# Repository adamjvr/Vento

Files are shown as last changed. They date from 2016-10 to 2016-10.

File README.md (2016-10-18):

# Vento
ARM Cortex M4F + WiFi+BLE + MPPT Solar Battery Powered module, mBed and Arduino Compatible hardware development
- ARM Cortex M4F 180MHZ STM32F446RET6
- ESP32 WiFi/BLE Dual Core SoC w/ PCB Antenna
- Bluetooth Classic
- Bluetooth Low Engergy (BLE)
- WiFi
- USB 2.0 Connectivity
- Plenty of GPIO
- PLenty of UART/I2C
- Lithium Ion Battery Power
- MPPT Solar battery charging
- USB bus power for desktop development
- Over the Air Programming
- Low power
- 2 Year Battery Life w/Single Cell Lithium Battery

Vento 0.1a KiCAD PCB
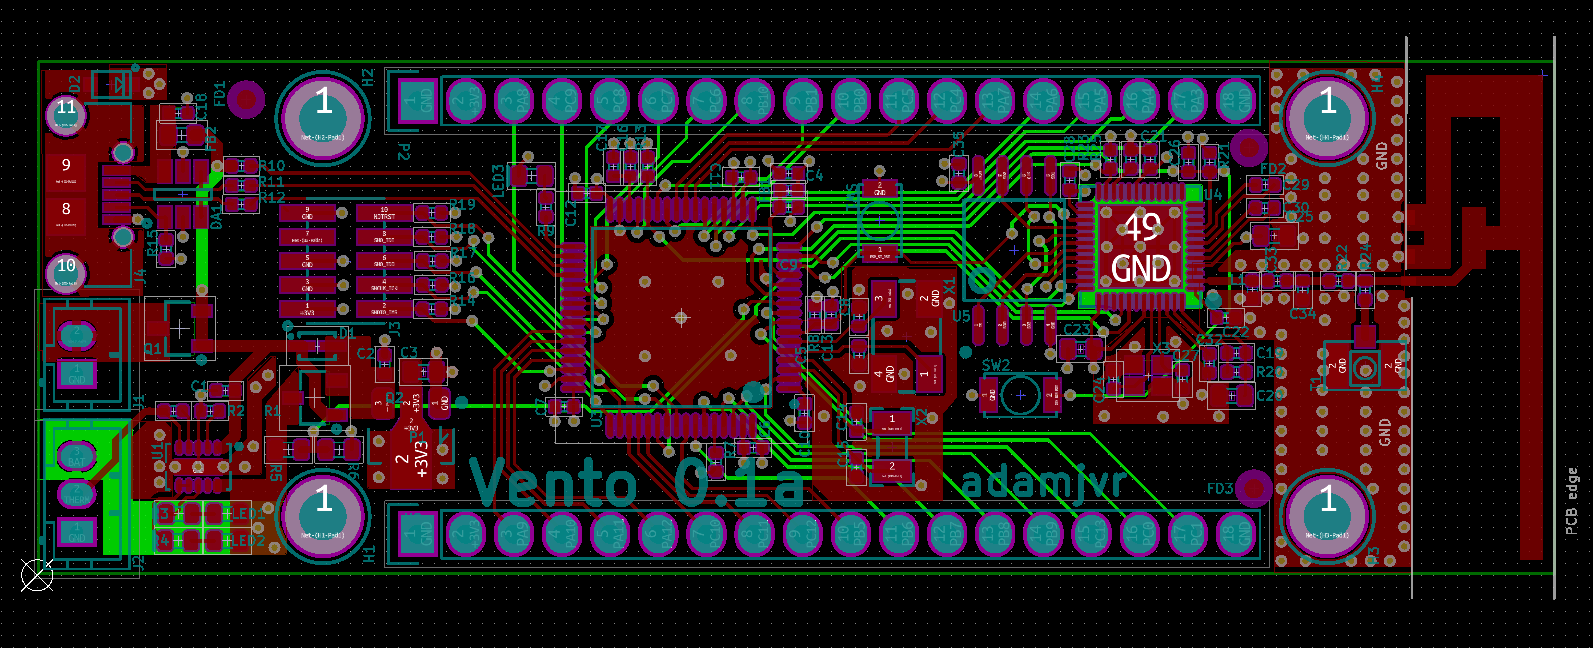
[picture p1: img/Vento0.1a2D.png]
Vento 0.1a KiCAD PCB

KiCAD PCB 3D Render
Top
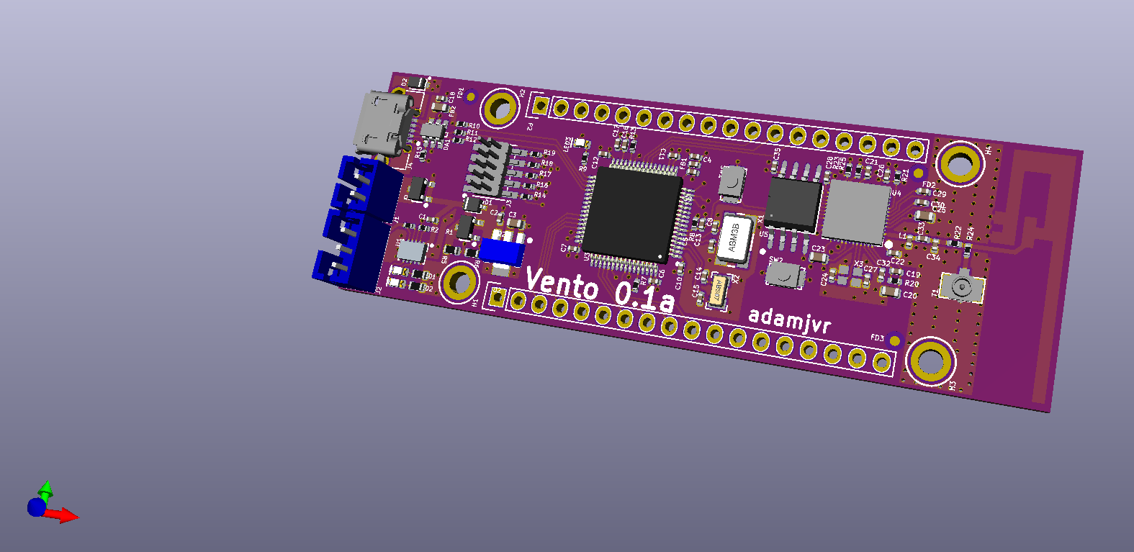
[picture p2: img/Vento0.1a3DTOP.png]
Vento 0.1a KiCAD 3D Top

Bottom
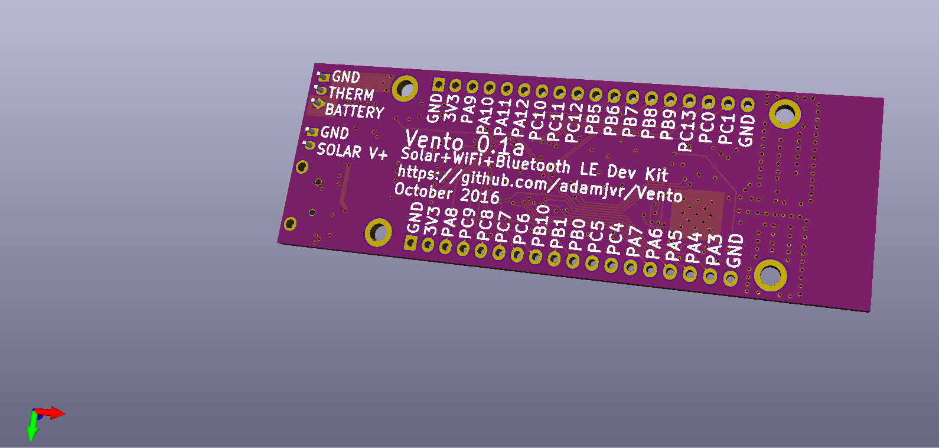
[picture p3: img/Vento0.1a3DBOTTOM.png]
Vento 0.1a KiCAD PCB


Vento 0.1a ESP3212 KiCAD PCB
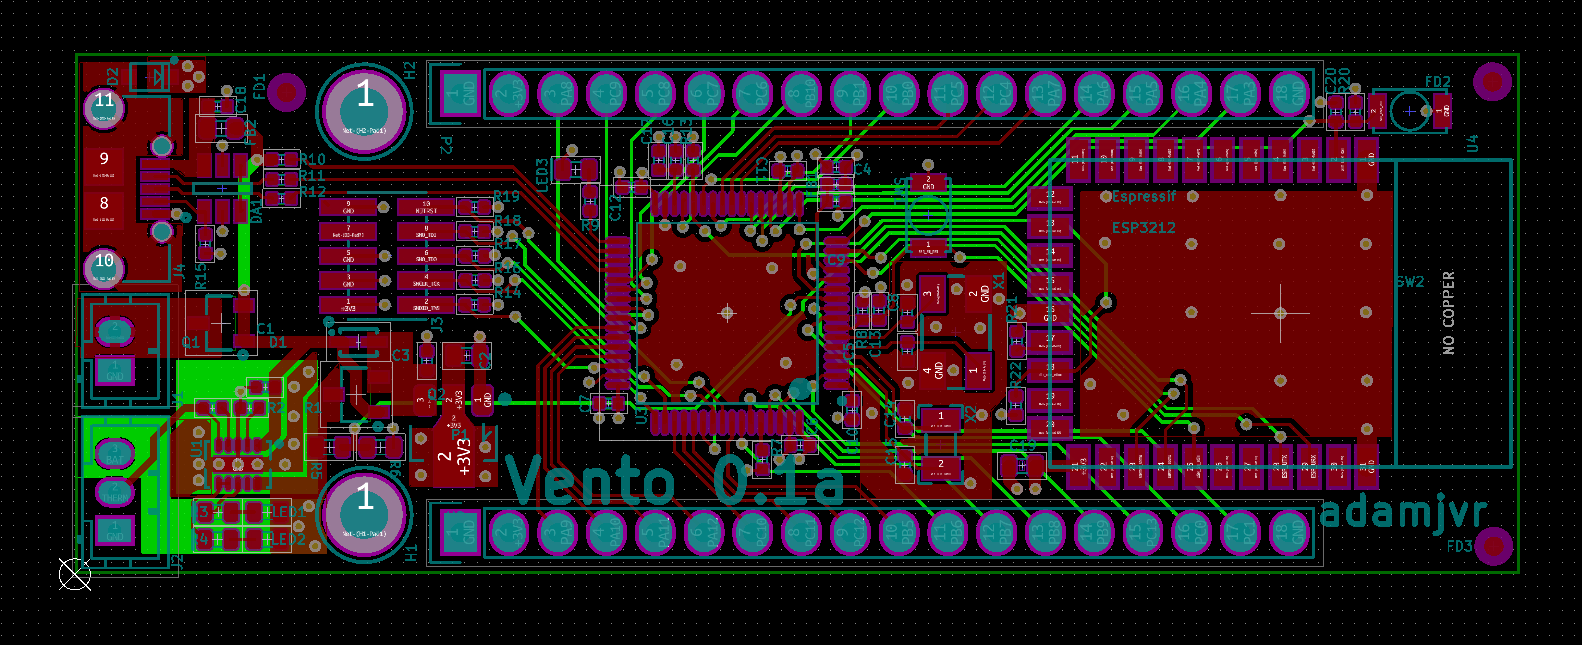
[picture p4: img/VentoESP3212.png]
Vento 0.1a ESP3212 KiCAD PCB


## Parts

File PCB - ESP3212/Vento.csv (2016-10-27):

Id | Designator | Package | Quantity | Designation | Supplier and ref
1 | C20,C4,C6,C7,C9,C10,C11,C12,C13,C17,C18 | C0402 | 11 | CL05B104JP5NNNC
2 | SW2,SW1 | B3U-1000P | 2 | B3U-1000P
3 | R21,R22,R7,R10,R13 | R0402 | 5 | RC1005F103CS
4 | R20 | R0402 | 1 | RC1005F123CS
5 | U4 | ESP3212 | 1 | ESP3212
6 | C19,C3 | C0603 | 2 | CL10A106KQ8NNNC
7 | P1,P2 | Socket_Strip_Straight_1x18 | 2 | CONN_01X18
8 | U1 | BQ24210 | 1 | BQ24210DQCT
9 | D1 | BAT20JFILM | 1 | BAT20JFILM
10 | Q1,Q2 | DMG2307L-7 | 2 | DMG2307L-7
11 | X2 | ABS07-32.768KHZ-9-T | 1 | ABS07-32.768KHZ-9-T
12 | D2 | RSB39VTE-17 | 1 | RSB39VTE-17
13 | DA1 | ESDA6V1BC6 | 1 | ESDA6V1BC6
14 | X1 | ABM3B8.000MHZB2T | 1 | ABM3B8.000MHZB2T
15 | FD1,FD2,FD3 | FIDUCIAL | 3 | FIDUCIAL
16 | H2,H1 | M2.5_HOLE | 2 | M2.5_Hole
17 | U3 | STM32F446RET6 | 1 | STM32F446RET6_-_TQFP64
18 | C1,C2 | C0402 | 2 | CL05A105KA5NQNC
19 | C5,C8 | C0402 | 2 | CL05C090CB5NNNC
20 | C14,C15 | C0402 | 2 | CL05C180GB5NCNC
21 | C16 | C0402 | 1 | CL05A475KQ5NRNC
22 | FB1 | BLM15HG601SN1D | 1 | BLM15HG601SN1D
23 | FB2 | MI0603K300R-10 | 1 | MI0603K300R-10
24 | J1 | B2B-PH-K-S(LF)(SN) | 1 | B2B-PH-K-S(LF)(SN)
25 | J2 | B3B-PH-K-S(LF)(SN) | 1 | B3B-PH-K-S(LF)(SN)
26 | J3 | 20021121-00010C4LF | 1 | 20021121-00010C4LF
27 | J4 | 0475890001 | 1 | 0475890001-MicroUSBPort
28 | LED1 | LED0603 | 1 | LTST-C191KGKT
29 | LED2 | LED0603 | 1 | LTST-C191KFKT
30 | LED3 | LED0603 | 1 | LTST-C193TBKT-5A
31 | R1 | R0402 | 1 | RC1005F4870CS
32 | R2,R8,R9,R14,R16,R17,R18,R19 | R0402 | 8 | RC1005F102CS
33 | R3,R4 | R0603 | 2 | RC1608J202CS
34 | R5,R6 | R0603 | 2 | ERA-3AEB3741V
35 | R11,R12 | R0402 | 2 | CPF0402B22RE1
36 | R15 | R0402 | 1 | RC1005J473CS
37 | U2 | AZ1117CR-3.3TRG1 | 1 | AZ1117CR-3.3TRG1_1

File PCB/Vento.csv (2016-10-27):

Id | Designator | Package | Quantity | Designation | Supplier and ref
1 | C26,C35,C32,C4,C6,C7,C9,C10,C11,C12,C13,C17,C18,C21,C22,C28 | C0402 | 16 | CL05B104JP5NNNC
2 | SW2,SW1 | B3U-1000P | 2 | B3U-1000P
3 | R25,R7,R10,R13,R21,R23 | R0402 | 6 | RC1005F103CS
4 | H4,H3,H2,H1 | M2.5_HOLE | 4 | M2.5_Hole
5 | C23,C25,C3 | C0603 | 3 | CL10A106KQ8NNNC
6 | U5 | W25Q64FWSSIG | 1 | W25Q64FWSSIG
7 | U4 | ESP32 | 1 | ESP32
8 | L1 | BLM15HG601SN1D | 1 | 744901027
9 | C29,C30 | C0402 | 2 | GRM1555C1H271FA01D
10 | C33 | C0402 | 1 | 600L3R9BT200T
11 | C34 | C0402 | 1 | 600L2R4BT200T
12 | C20 | C0603 | 1 | C0603C103J5JAC7867
13 | ANT1 | PCB_IF_ANT_2.4G | 1 | Inverted_F_PCB_Antenna
14 | R24,R22 | R0402 | 2 | ERJ-2GE0R00X
15 | P1,P2 | Socket_Strip_Straight_1x18 | 2 | CONN_01X18
16 | U1 | BQ24210 | 1 | BQ24210DQCT
17 | D1 | BAT20JFILM | 1 | BAT20JFILM
18 | Q1,Q2 | DMG2307L-7 | 2 | DMG2307L-7
19 | X2 | ABS07-32.768KHZ-9-T | 1 | ABS07-32.768KHZ-9-T
20 | D2 | RSB39VTE-17 | 1 | RSB39VTE-17
21 | DA1 | ESDA6V1BC6 | 1 | ESDA6V1BC6
22 | X1 | ABM3B8.000MHZB2T | 1 | ABM3B8.000MHZB2T
23 | FD1,FD2,FD3 | FIDUCIAL | 3 | FIDUCIAL
24 | U3 | STM32F446RET6 | 1 | STM32F446RET6_-_TQFP64
25 | C1,C2 | C0402 | 2 | CL05A105KA5NQNC
26 | C5,C8,C24,C27 | C0402 | 4 | CL05C090CB5NNNC
27 | C14,C15 | C0402 | 2 | CL05C180GB5NCNC
28 | C16 | C0402 | 1 | CL05A475KQ5NRNC
29 | C19 | C0402 | 1 | GRM1557U1A302JA01D
30 | FB1 | BLM15HG601SN1D | 1 | BLM15HG601SN1D
31 | FB2 | MI0603K300R-10 | 1 | MI0603K300R-10
32 | J1 | B2B-PH-K-S(LF)(SN) | 1 | B2B-PH-K-S(LF)(SN)
33 | J2 | B3B-PH-K-S(LF)(SN) | 1 | B3B-PH-K-S(LF)(SN)
34 | J3 | 20021121-00010C4LF | 1 | 20021121-00010C4LF
35 | J4 | 0475890001 | 1 | 0475890001-MicroUSBPort
36 | LED1 | LED0603 | 1 | LTST-C191KGKT
37 | LED2 | LED0603 | 1 | LTST-C191KFKT
38 | LED3 | LED0603 | 1 | LTST-C193TBKT-5A
39 | R1 | R0402 | 1 | RC1005F4870CS
40 | R2,R8,R9,R14,R16,R17,R18,R19 | R0402 | 8 | RC1005F102CS
41 | R3,R4 | R0603 | 2 | RC1608J202CS
42 | R5,R6 | R0603 | 2 | ERA-3AEB3741V
43 | R11,R12 | R0402 | 2 | CPF0402B22RE1
44 | R15 | R0402 | 1 | RC1005J473CS
45 | R20 | R0402 | 1 | RC1005F203CS
46 | T1 | 1909763-1 | 1 | 1909763-1
47 | U2 | AZ1117CR-3.3TRG1 | 1 | AZ1117CR-3.3TRG1_1
48 | X3 | FA-128_26.0000MF10Z-AC3 | 1 | FA-128_26.0000MF10Z-AC3

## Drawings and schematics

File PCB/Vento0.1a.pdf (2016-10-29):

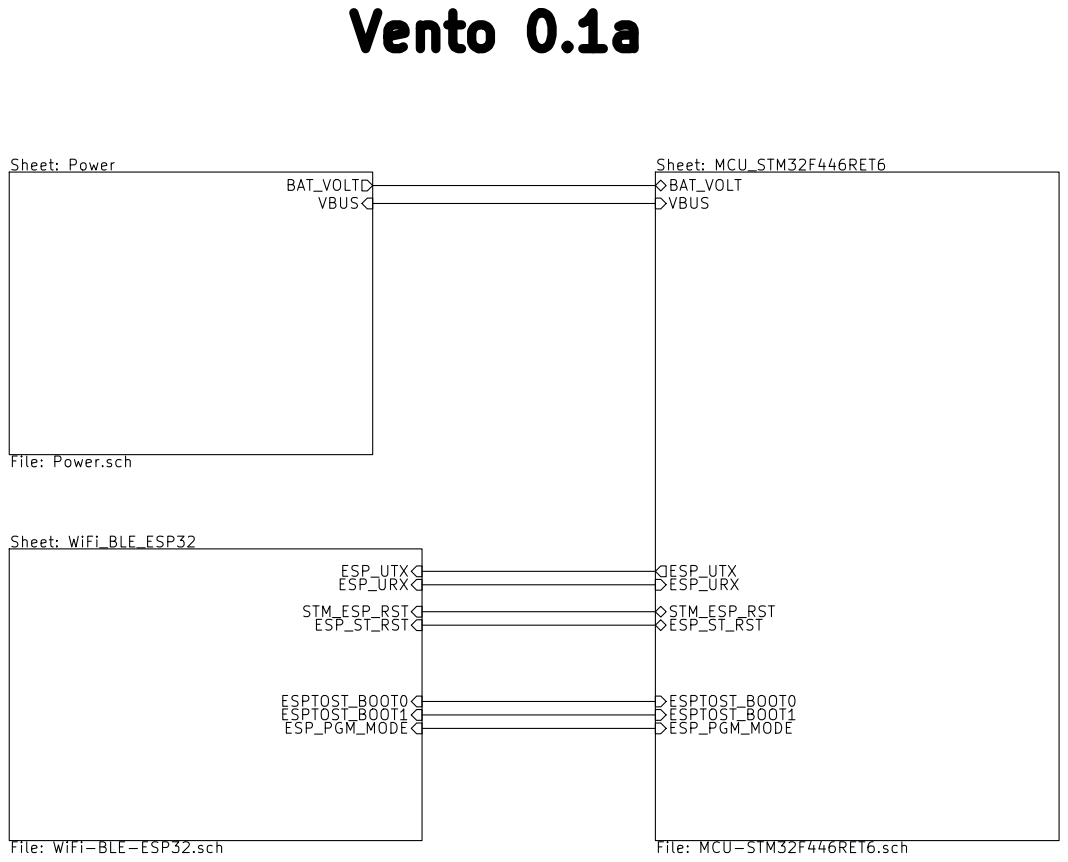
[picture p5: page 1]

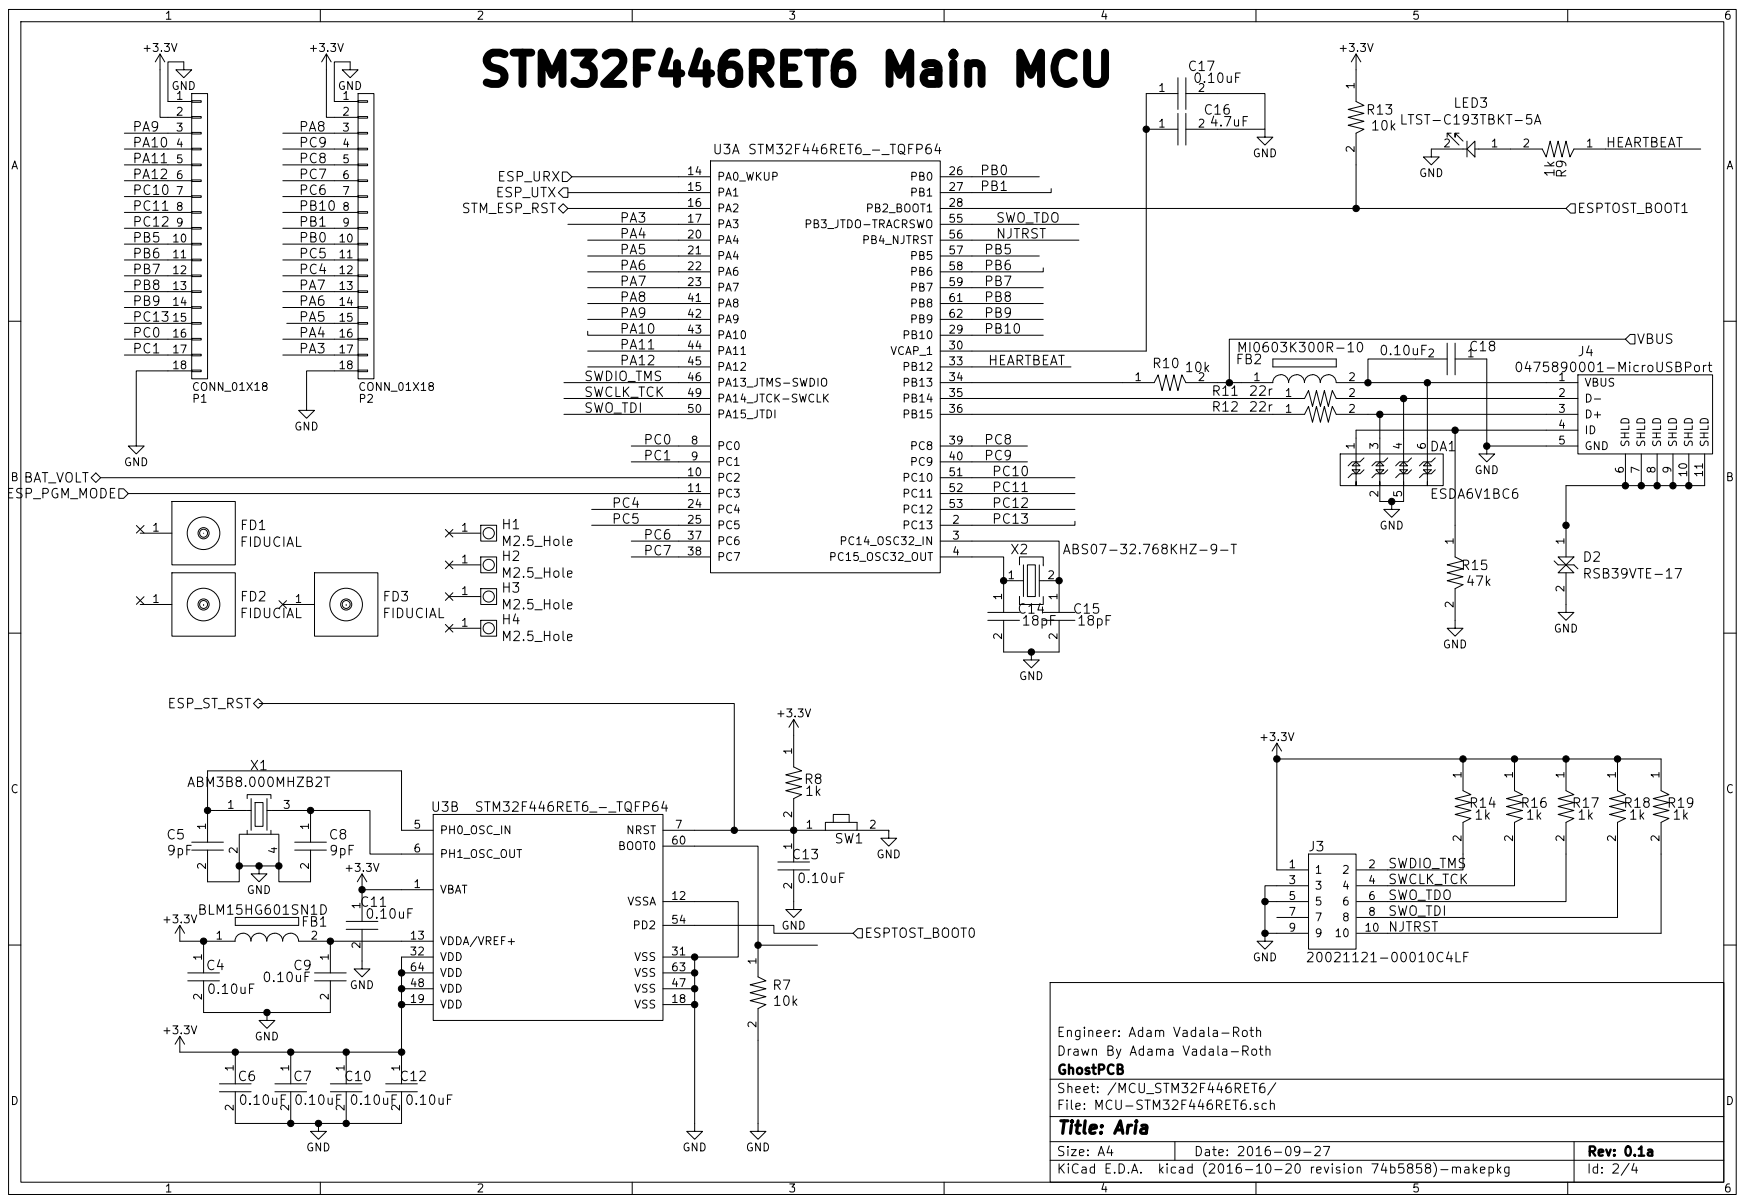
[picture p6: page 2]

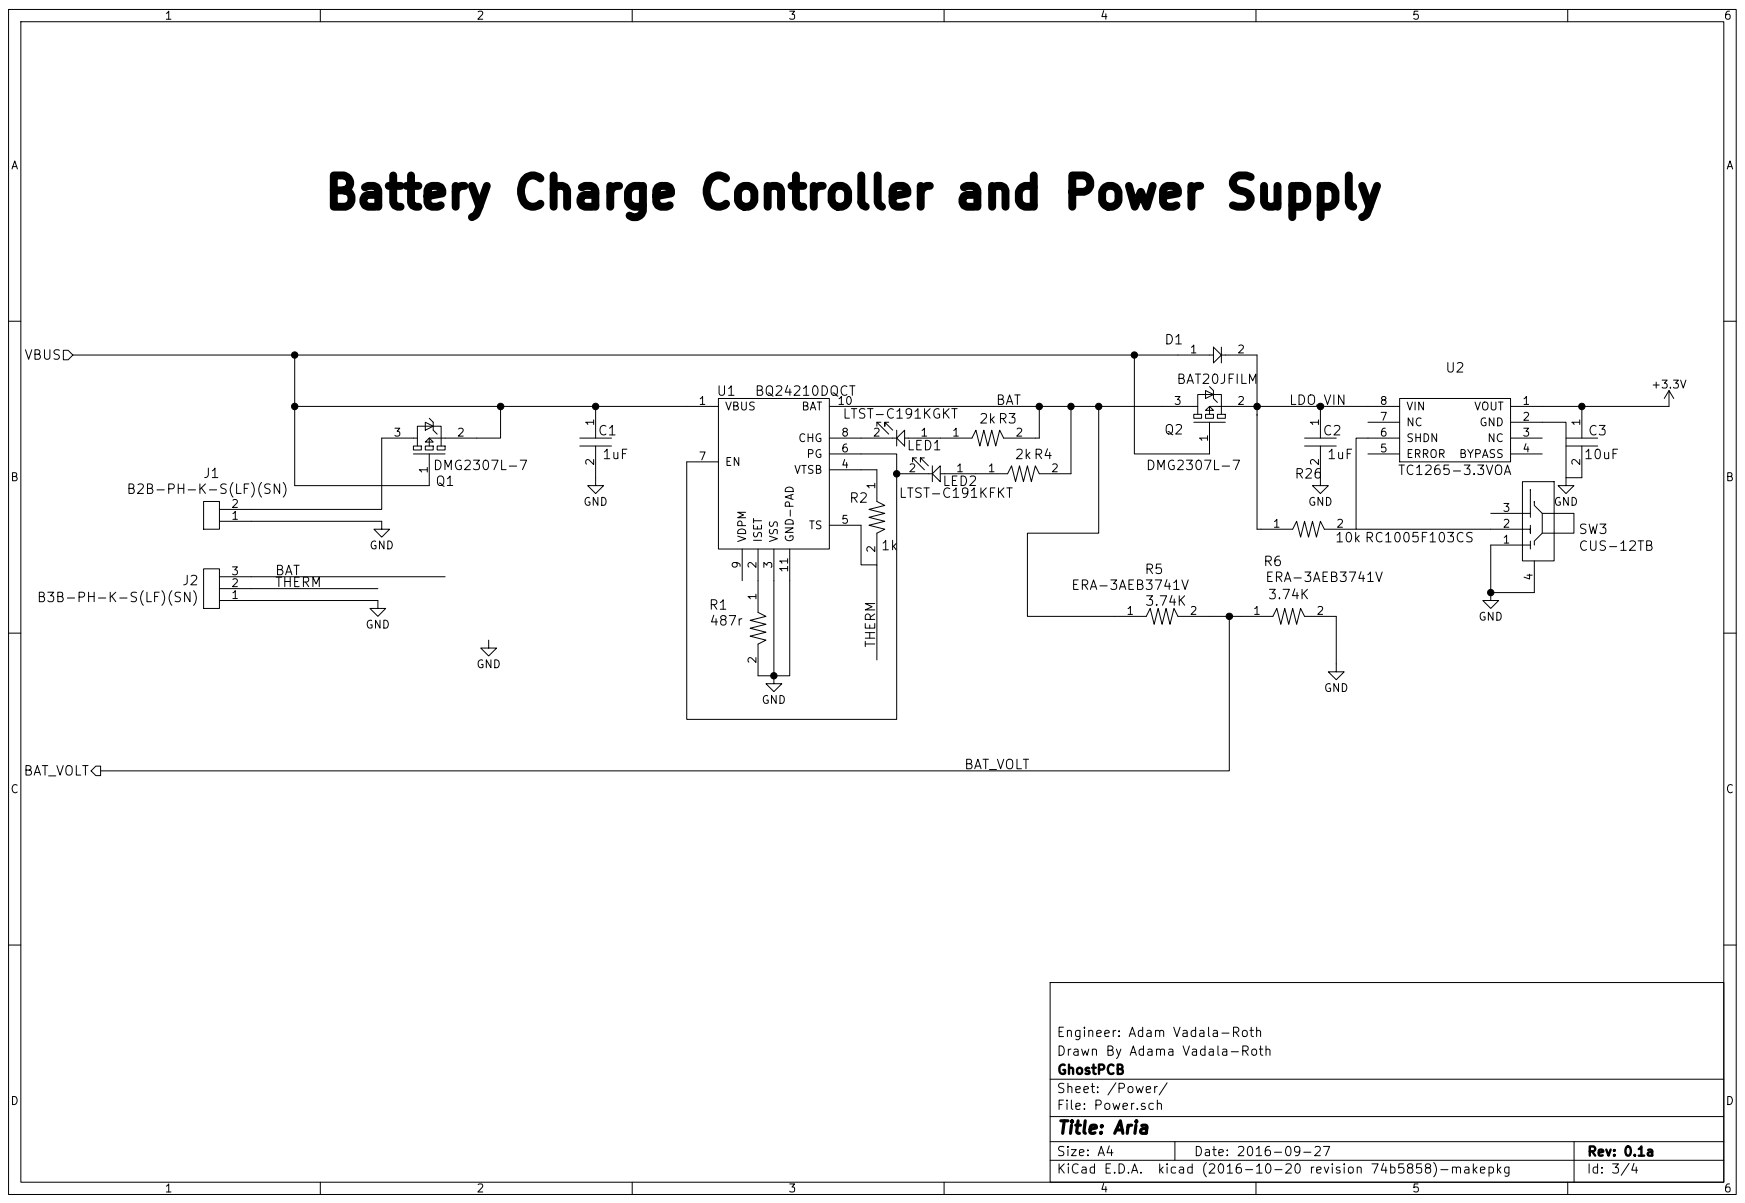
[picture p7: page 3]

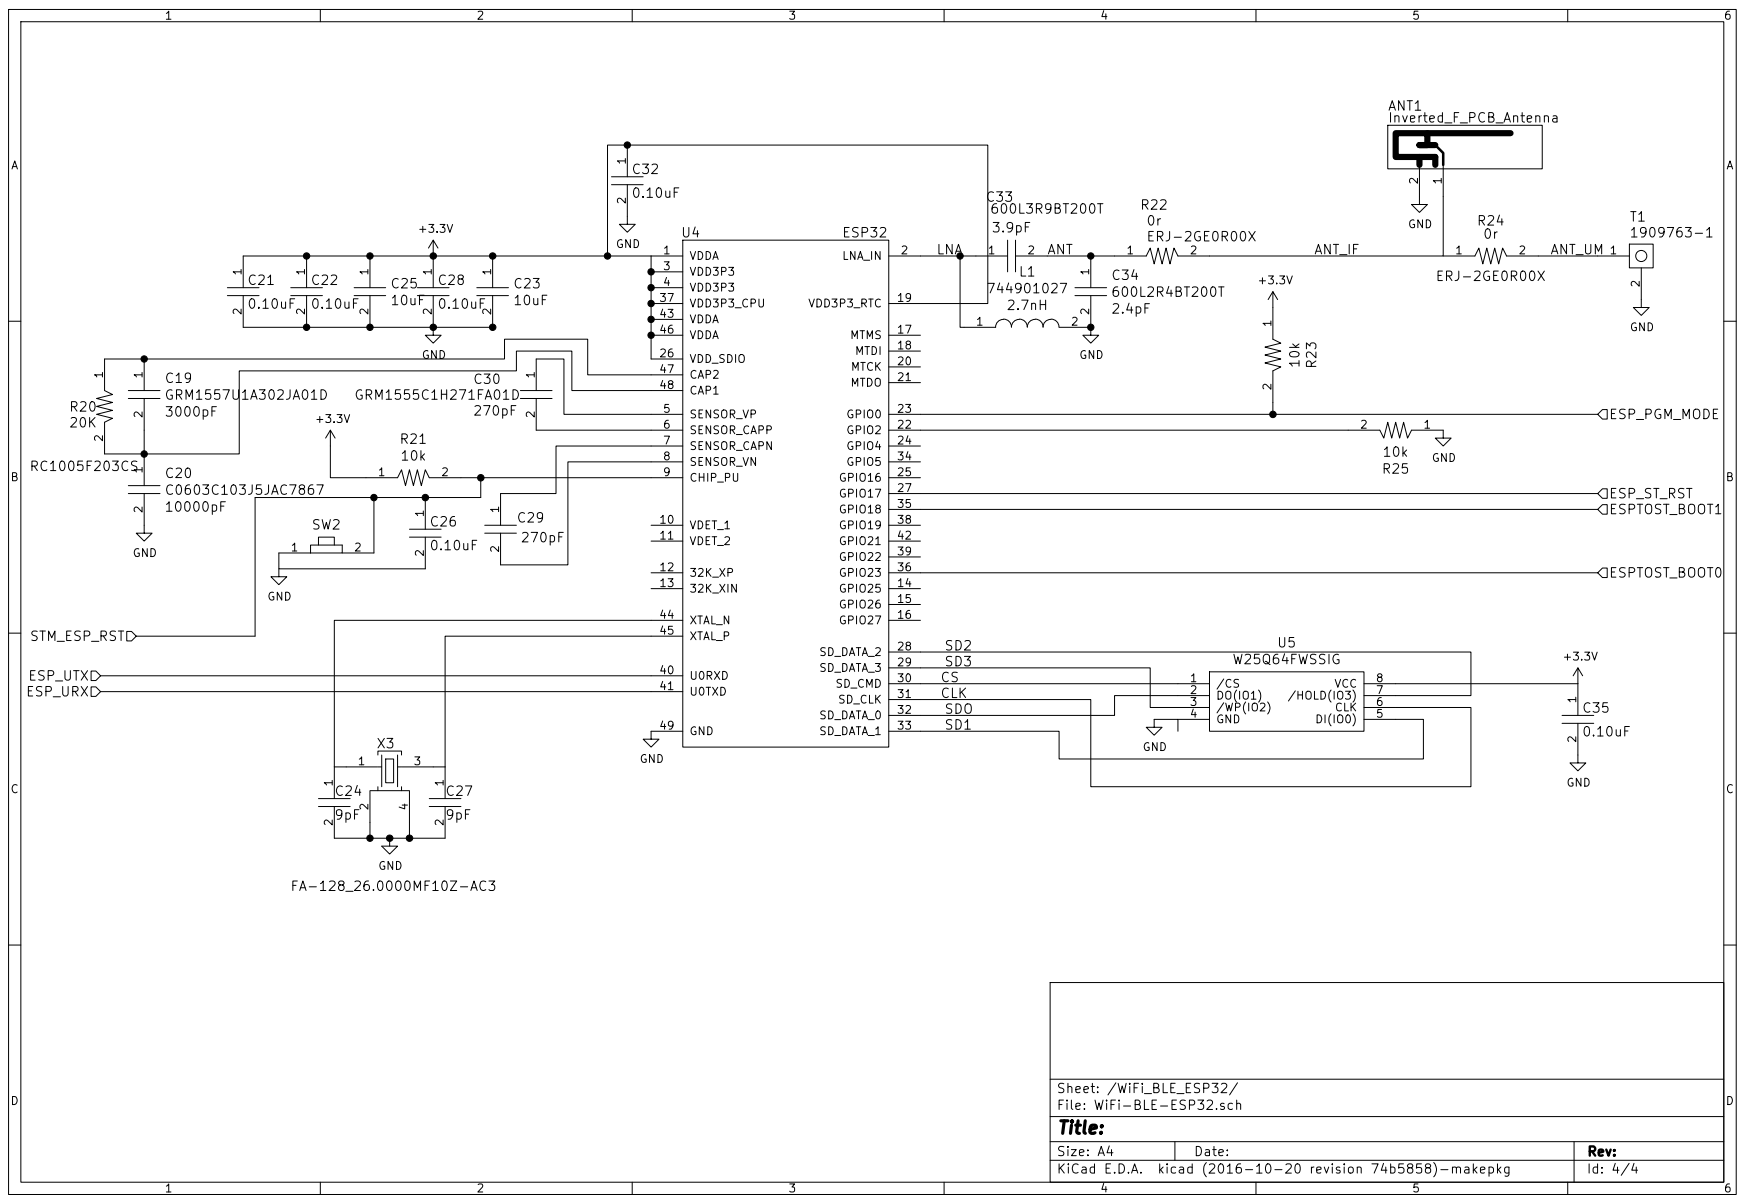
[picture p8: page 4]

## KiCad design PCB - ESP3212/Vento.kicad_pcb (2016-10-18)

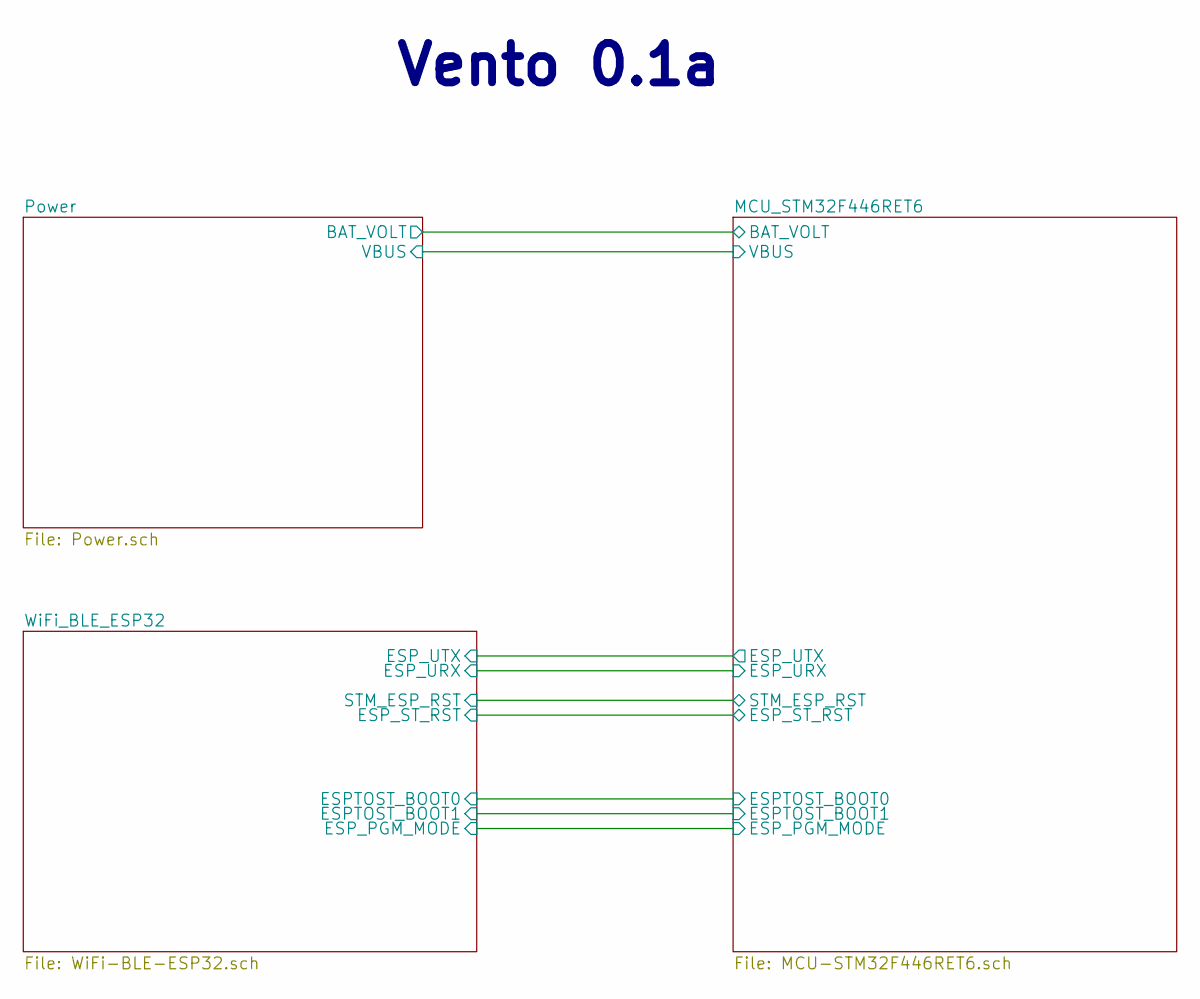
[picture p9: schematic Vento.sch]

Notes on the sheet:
Vento 0.1a

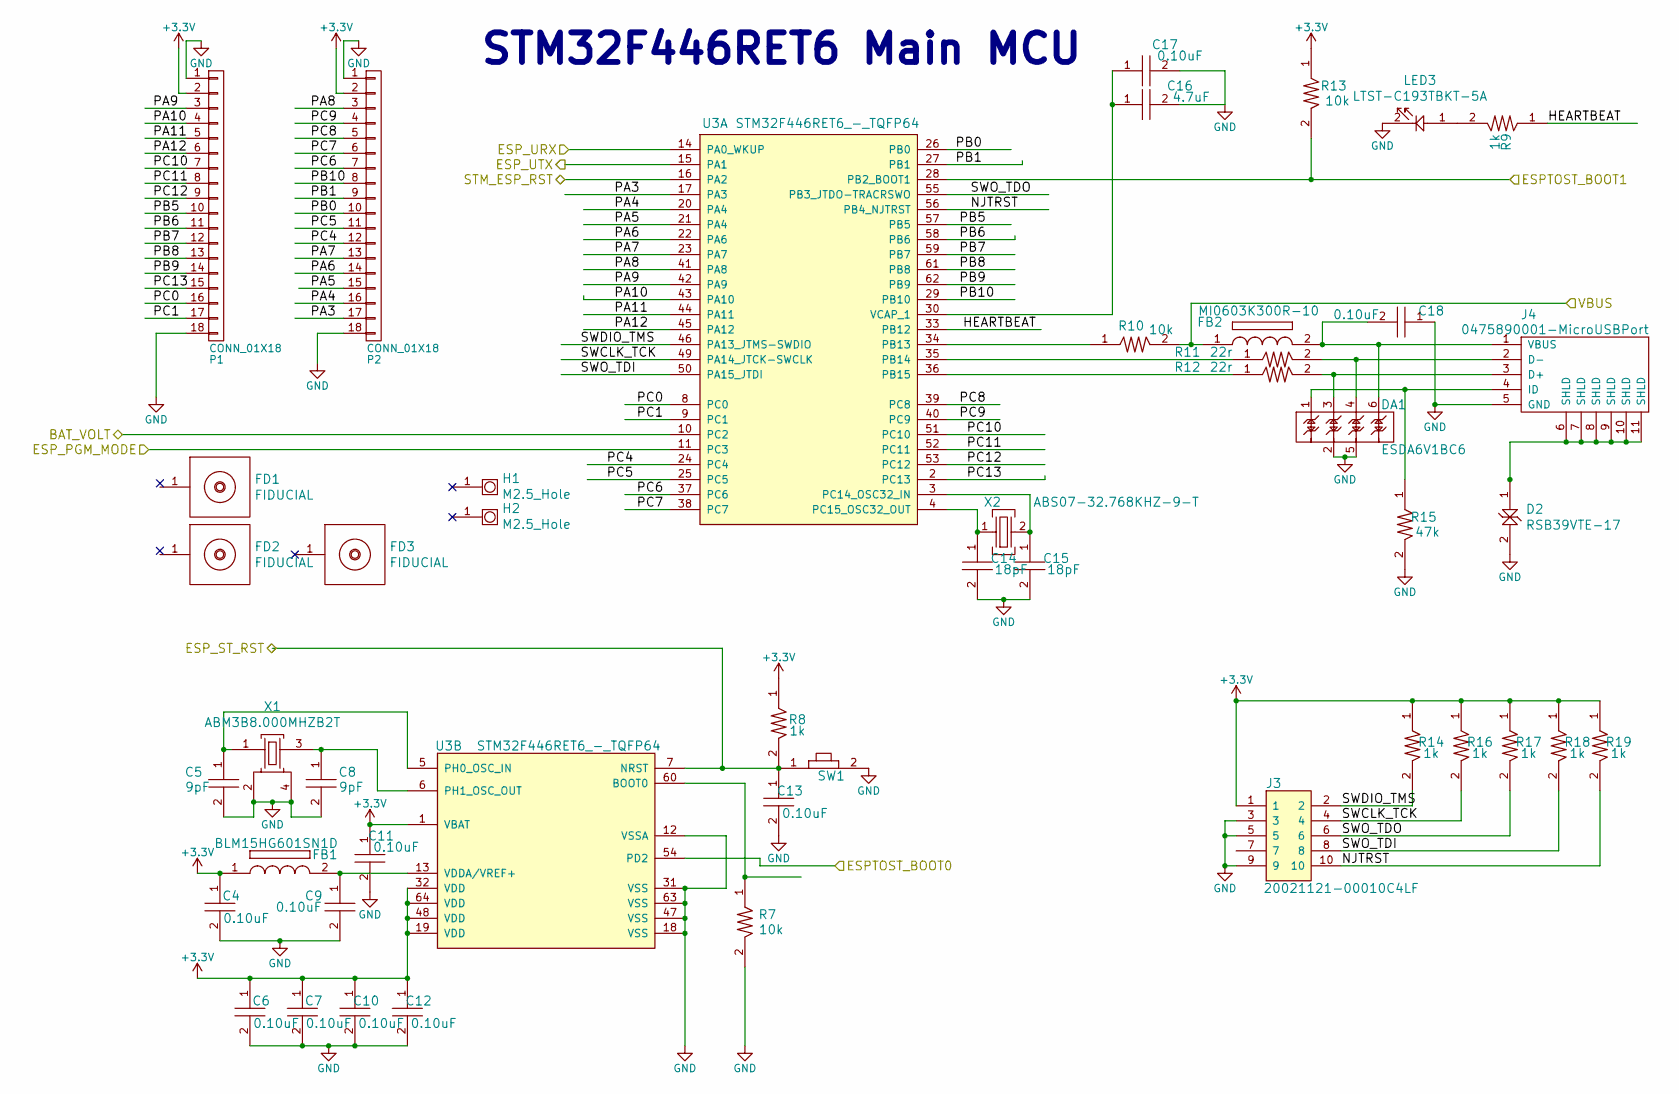
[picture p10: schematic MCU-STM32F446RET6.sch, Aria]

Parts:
C4, C6, C7, C9, C10, C11, C12, C13, C17, C18: CL05B104JP5NNNC; C0402; Tolerance 5%; Voltage 10V; MFR# CL05B104JP5NNNC
C5, C8: CL05C090CB5NNNC; C0402; Tolerance 0.25pF; Voltage 50V; MFR# CL05C090CB5NNNC
C14, C15: CL05C180GB5NCNC; C0402; Tolerance 2%; Voltage 50V; MFR# CL05C180GB5NCNC
C16: CL05A475KQ5NRNC; C0402; Tolerance 10%; Voltage 25V; MFR# CL05A475KQ5NRNC
D2: RSB39VTE-17; Tolerance N/A; Voltage 30V; MFR# RSB39VTE-17
DA1: ESDA6V1BC6; Tolerance N/A; Voltage 4V; MFR# ESDA6V1BC6
FB1: BLM15HG601SN1D; Tolerance N/A; Voltage N/A; MFR# BLM15HG601SN1D
FB2: MI0603K300R-10; Tolerance N/A; Voltage N/A; MFR# MI0603K300R-10
FD1, FD2, FD3: FIDUCIAL
H1, H2: M2.5_Hole; M2.5_HOLE
J3: 20021121-00010C4LF; Tolerance N/A; Voltage 200V MAX; MFR# 20021121-00010C4LF
J4: 0475890001-MicroUSBPort; 0475890001; Tolerance N/A; Voltage 5V; MFR# 0475890001
LED3: LTST-C193TBKT-5A; LED0603; Tolerance N/A; Voltage 2.8V Forward Voltage; MFR# LTST-C193TBKT-5A
P1, P2: CONN_01X18
R7, R10, R13: RC1005F103CS; R0402; Tolerance 1%; Voltage N/A; MFR# RC1005F103CS
R8, R9, R14, R16, R17, R18, R19: RC1005F102CS; R0402; Tolerance %; Voltage N/A; MFR# RC1005F102CS
R11, R12: CPF0402B22RE1; R0402; Tolerance 0.1%; Voltage N/A; MFR# CPF0402B22RE1
R15: RC1005J473CS; R0402; Tolerance 5%; Voltage N/A; MFR# RC1005J473CS
SW1: B3U-1000P; Tolerance %; Voltage 50V; MFR# B3U-1000P
U3: STM32F446RET6_-_TQFP64; STM32F446RET6; Tolerance N/A; Voltage 1.8-3.3V; MFR# STM32F446RET6
X1: ABM3B8.000MHZB2T; Tolerance N/A; Voltage 3.3V; MFR# ABM3B-8.000MHZ-B2-T
X2: ABS07-32.768KHZ-9-T; Tolerance ±20ppm; Voltage N/A; MFR# ABS07-32.768KHZ-9-T

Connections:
+3V3: C4.1, C6.1, C7.1, C10.1, C11.1, C12.1, FB1.1, J3.1, P1.2, P2.2, R8.1, R13.1, R14.1, R16.1, R17.1, R18.1, R19.1, U3.1 (VBAT), U3.19 (VDD), U3.32 (VDD), U3.48 (VDD), U3.64 (VDD); also elsewhere on the board
/MCU_STM32F446RET6/BAT_VOLT: U3.10 (PC2); also elsewhere on the board
/MCU_STM32F446RET6/ESPTOST_BOOT0: U3.54 (PD2); also elsewhere on the board
/MCU_STM32F446RET6/ESPTOST_BOOT1: R13.2, U3.28 (PB2_BOOT1); also elsewhere on the board
/MCU_STM32F446RET6/ESP_PGM_MODE: U3.11 (PC3); also elsewhere on the board
/MCU_STM32F446RET6/ESP_ST_RST: C13.1, R8.2, SW1.1, U3.7 (NRST); also elsewhere on the board
/MCU_STM32F446RET6/ESP_URX: U3.14 (PA0_WKUP); also elsewhere on the board
/MCU_STM32F446RET6/ESP_UTX: U3.15 (PA1); also elsewhere on the board
/MCU_STM32F446RET6/HEARTBEAT: R9.1, U3.33 (PB12)
/MCU_STM32F446RET6/NJTRST: J3.10, R19.2, U3.56 (PB4_NJTRST)
/MCU_STM32F446RET6/PA3: P2.17, U3.17 (PA3)
/MCU_STM32F446RET6/PA4: P2.16, U3.20 (PA4)
/MCU_STM32F446RET6/PA5: P2.15, U3.21 (PA4)
/MCU_STM32F446RET6/PA6: P2.14, U3.22 (PA6)
/MCU_STM32F446RET6/PA7: P2.13, U3.23 (PA7)
/MCU_STM32F446RET6/PA8: P2.3, U3.41 (PA8)
/MCU_STM32F446RET6/PA9: P1.3, U3.42 (PA9)
/MCU_STM32F446RET6/PA10: P1.4, U3.43 (PA10)
/MCU_STM32F446RET6/PA11: P1.5, U3.44 (PA11)
/MCU_STM32F446RET6/PA12: P1.6, U3.45 (PA12)
/MCU_STM32F446RET6/PB0: P2.10, U3.26 (PB0)
/MCU_STM32F446RET6/PB1: P2.9, U3.27 (PB1)
/MCU_STM32F446RET6/PB5: P1.10, U3.57 (PB5)
/MCU_STM32F446RET6/PB6: P1.11, U3.58 (PB6)
/MCU_STM32F446RET6/PB7: P1.12, U3.59 (PB7)
/MCU_STM32F446RET6/PB8: P1.13, U3.61 (PB8)
/MCU_STM32F446RET6/PB9: P1.14, U3.62 (PB9)
/MCU_STM32F446RET6/PB10: P2.8, U3.29 (PB10)
/MCU_STM32F446RET6/PC0: P1.16, U3.8 (PC0)
/MCU_STM32F446RET6/PC1: P1.17, U3.9 (PC1)
/MCU_STM32F446RET6/PC4: P2.12, U3.24 (PC4)
/MCU_STM32F446RET6/PC5: P2.11, U3.25 (PC5)
/MCU_STM32F446RET6/PC6: P2.7, U3.37 (PC6)
/MCU_STM32F446RET6/PC7: P2.6, U3.38 (PC7)
/MCU_STM32F446RET6/PC8: P2.5, U3.39 (PC8)
/MCU_STM32F446RET6/PC9: P2.4, U3.40 (PC9)
/MCU_STM32F446RET6/PC10: P1.7, U3.51 (PC10)
/MCU_STM32F446RET6/PC11: P1.8, U3.52 (PC11)
/MCU_STM32F446RET6/PC12: P1.9, U3.53 (PC12)
/MCU_STM32F446RET6/PC13: P1.15, U3.2 (PC13)
/MCU_STM32F446RET6/STM_ESP_RST: U3.16 (PA2); also elsewhere on the board
/MCU_STM32F446RET6/SWCLK_TCK: J3.4, R16.2, U3.49 (PA14_JTCK-SWCLK)
/MCU_STM32F446RET6/SWDIO_TMS: J3.2, R14.2, U3.46 (PA13_JTMS-SWDIO)
/MCU_STM32F446RET6/SWO_TDI: J3.8, R18.2, U3.50 (PA15_JTDI)
/MCU_STM32F446RET6/SWO_TDO: J3.6, R17.2, U3.55 (PB3_JTDO-TRACRSWO)
/MCU_STM32F446RET6/VBUS: FB2.1, R10.2; also elsewhere on the board
GND: C4.2, C5.2, C6.2, C7.2, C8.2, C9.2, C10.2, C11.2, C12.2, C13.2, C14.2, C15.2, C16.2, C17.2, C18.1, D2.2, DA1.2, DA1.5, J3.3, J3.5, J3.9, J4.5 (GND), LED3.2, P1.1, P1.18, P2.1, P2.18, R7.2, R15.2, SW1.2, U3.12 (VSSA), U3.18 (VSS), U3.31 (VSS), U3.47 (VSS), U3.63 (VSS), X1.2, X1.4; also elsewhere on the board
unnamed: C5.1, U3.5 (PH0_OSC_IN), X1.1
unnamed: C8.1, U3.6 (PH1_OSC_OUT), X1.3
unnamed: C9.1, FB1.2, U3.13 (VDDA/VREF+)
unnamed: C14.1, U3.4 (PC15_OSC32_OUT), X2.1
unnamed: C15.1, U3.3 (PC14_OSC32_IN), X2.2
unnamed: C16.1, C17.1, U3.30 (VCAP_1)
unnamed: C18.2, DA1.6, FB2.2, J4.1 (VBUS)
unnamed: D2.1, J4.6 (SHLD), J4.7 (SHLD), J4.8 (SHLD), J4.9 (SHLD), J4.10 (SHLD), J4.11 (SHLD)
unnamed: DA1.1, J4.4 (ID), R15.1
unnamed: DA1.3, J4.3 (D+), R12.2
unnamed: DA1.4, J4.2 (D-), R11.2
unnamed: LED3.1, R9.2
unnamed: R7.1, U3.60 (BOOT0)
unnamed: R10.1, U3.34 (PB13)
unnamed: R11.1, U3.35 (PB14)
unnamed: R12.1, U3.36 (PB15)

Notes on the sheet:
STM32F446RET6 Main MCU

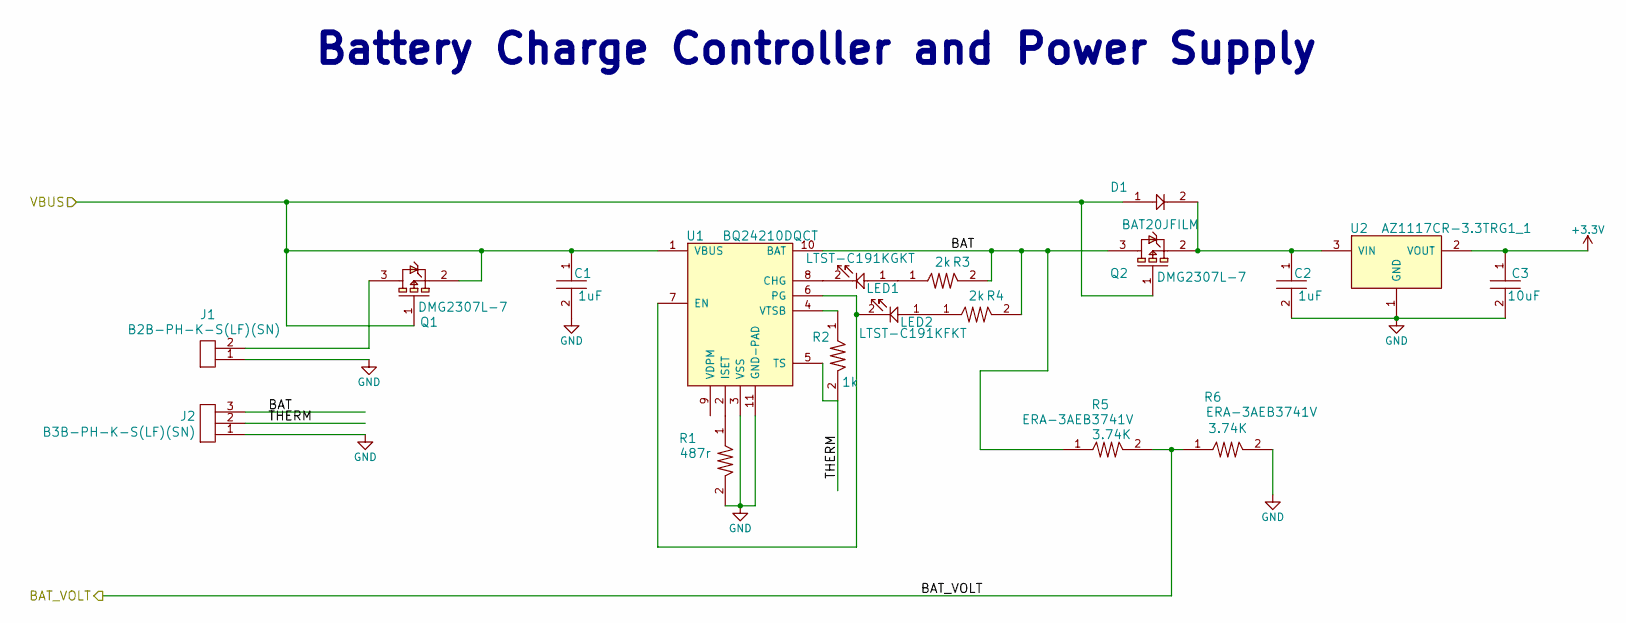
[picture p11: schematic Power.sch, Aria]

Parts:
C1, C2: CL05A105KA5NQNC; C0402; Tolerance 10%; Voltage 25V; MFR# CL05A105KA5NQNC
C3: CL10A106KQ8NNNC; C0603; Tolerance 10%; Voltage 6.3V; MFR# CL10A106KQ8NNNC
D1: BAT20JFILM; Tolerance N/A; Voltage N/A; MFR# BAT20JFILM
J1: B2B-PH-K-S(LF)(SN); Tolerance N/A; Voltage N/A; MFR# B2B-PH-K-S(LF)(SN)
J2: B3B-PH-K-S(LF)(SN); Tolerance N/A; Voltage N/A; MFR# B3B-PH-K-S(LF)(SN)
LED1: LTST-C191KGKT; LED0603; Tolerance N/A; Voltage N/A; MFR# LTST-C191KGKT
LED2: LTST-C191KFKT; LED0603; Tolerance N/A; Voltage N/A; MFR# LTST-C191KFKT
Q1, Q2: DMG2307L-7; Tolerance N/A; Voltage 30V; MFR# DMG2307L-7
R1: RC1005F4870CS; R0402; Tolerance 1%; Voltage N/A; MFR# RC1005F4870CS
R2: RC1005F102CS; R0402; Tolerance %; Voltage N/A; MFR# RC1005F102CS
R3, R4: RC1608J202CS; R0603; Tolerance 1%; Voltage N/A; MFR# RC1608F202CS
R5, R6: ERA-3AEB3741V; R0603; Tolerance 1%; Voltage N/A; MFR# ERA-3AEB3741V
U1: BQ24210DQCT; BQ24210; Tolerance N/A; Voltage 3.5-18VDC; MFR# BQ24210DQCT
U2: AZ1117CR-3.3TRG1_1; AZ1117CR-3.3TRG1; Tolerance N/A; Voltage 3.7V input 3.3V Output; MFR# AZ1117CR-3.3TRG1

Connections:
+3V3: C3.1, U2.2 (VOUT); also elsewhere on the board
/MCU_STM32F446RET6/BAT_VOLT: R5.2, R6.1; also elsewhere on the board
/MCU_STM32F446RET6/VBUS: C1.1, D1.1, Q1.1, Q1.2, Q2.1, U1.1 (VBUS); also elsewhere on the board
/Power/BAT: J2.3, Q2.3, R3.2, R4.2, R5.1, U1.10 (BAT)
/Power/THERM: J2.2, R2.2, U1.5 (TS)
GND: C1.2, C2.2, C3.2, J1.1, J2.1, R1.2, R6.2, U1.3 (VSS), U1.11 (GND-PAD), U2.1 (GND); also elsewhere on the board
unnamed: C2.1, D1.2, Q2.2, U2.3 (VIN)
unnamed: J1.2, Q1.3
unnamed: LED1.1, R3.1
unnamed: LED1.2, U1.8 (CHG)
unnamed: LED2.1, R4.1
unnamed: LED2.2, U1.6 (PG), U1.7 (EN)
unnamed: R1.1, U1.2 (ISET)
unnamed: R2.1, U1.4 (VTSB)

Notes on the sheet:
Battery Charge Controller and Power Supply

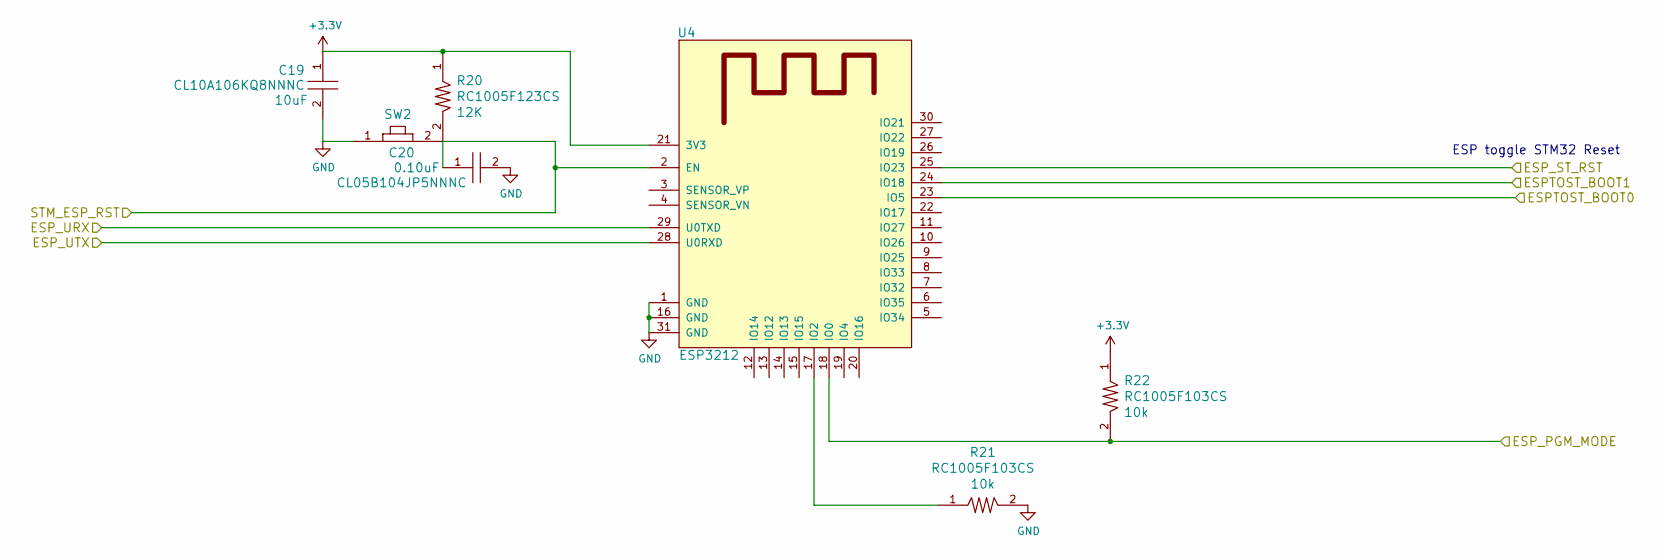
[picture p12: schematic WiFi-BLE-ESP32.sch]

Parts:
C19: CL10A106KQ8NNNC; C0603; Tolerance 10%; Voltage 6.3V; MFR# CL10A106KQ8NNNC
C20: CL05B104JP5NNNC; C0402; Tolerance 5%; Voltage 10V; MFR# CL05B104JP5NNNC
R20: RC1005F123CS; R0402; Tolerance %; Voltage N/A; MFR# RC1005F123CS
R21, R22: RC1005F103CS; R0402; Tolerance 1%; Voltage N/A; MFR# RC1005F103CS
SW2: B3U-1000P; Tolerance %; Voltage 50V; MFR# B3U-1000P
U4: ESP3212

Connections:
+3V3: C19.1, R20.1, R22.1, U4.21 (3V3); also elsewhere on the board
/MCU_STM32F446RET6/ESPTOST_BOOT0: U4.23 (IO5); also elsewhere on the board
/MCU_STM32F446RET6/ESPTOST_BOOT1: U4.24 (IO18); also elsewhere on the board
/MCU_STM32F446RET6/ESP_PGM_MODE: R22.2, U4.18 (IO0); also elsewhere on the board
/MCU_STM32F446RET6/ESP_ST_RST: U4.25 (IO23); also elsewhere on the board
/MCU_STM32F446RET6/ESP_URX: U4.29 (U0TXD); also elsewhere on the board
/MCU_STM32F446RET6/ESP_UTX: U4.28 (U0RXD); also elsewhere on the board
/MCU_STM32F446RET6/STM_ESP_RST: C20.1, R20.2, SW2.2, U4.2 (EN); also elsewhere on the board
GND: C19.2, C20.2, R21.2, SW2.1, U4.1 (GND), U4.16 (GND), U4.31 (GND); also elsewhere on the board
unnamed: R21.1, U4.17 (IO2)

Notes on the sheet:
ESP toggle STM32 Reset

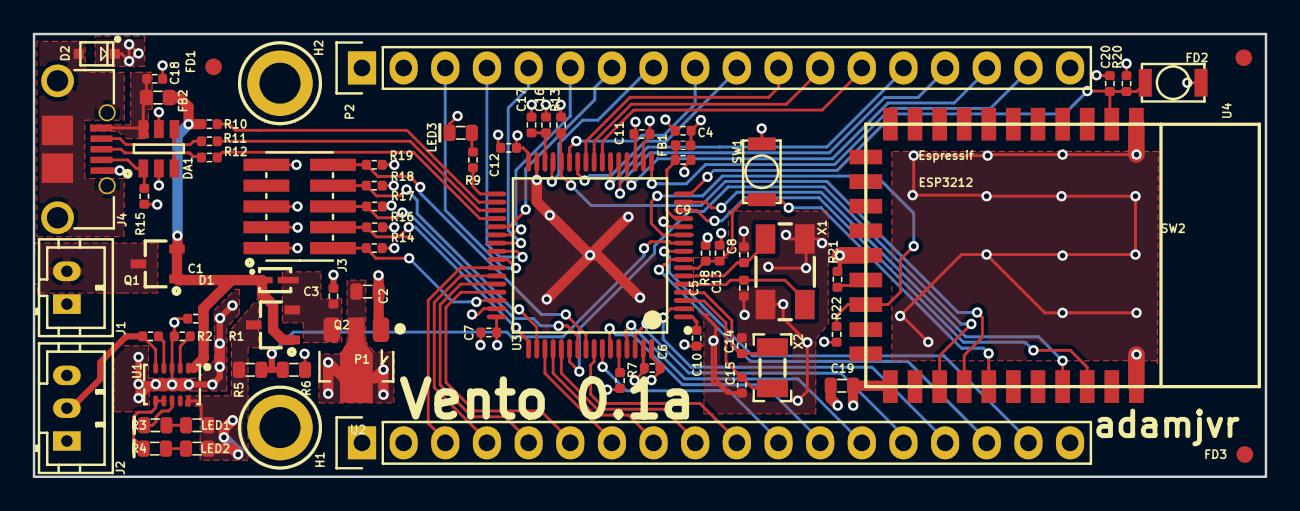
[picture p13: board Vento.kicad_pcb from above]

Board: 4 copper layers, 75.1 x 27.0 mm, 71 parts (0 on the bottom side), 74 nets.

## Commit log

2016-09-27 Schematic Development
    Schematic development still underway. Working on ESP32 section.
    [MCU-STM32F446RET6.sch, Power.sch, Vento.kicad_pcb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]
2016-10-14 Schematic Done, Board Underway
    Schematic completed. STM32 section upated from Aria project schematic,
    ESP32 schematic completed with the help of reference schematic.
    Datasheets for componens used also added. The PCB is near complete, Aria
    was improted and modifed to speed up the process. More to come!
    [MCU-STM32F446RET6.sch, Power.sch, Vento.sch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]
2016-10-14 Progress
    Headers routed, going to switch SPI flash on ESP32 circuit to SOIC model
    for simpler routing.
    [Vento.kicad_pcb]
2016-10-14 PCB
    PCB done
    [Vento.kicad_pcb, _saved_WiFi-BLE-ESP32.sch]
2016-10-16 Tweaking and ESP3212 version
    Continuing to tweak the PCB, for optimal RF performance, thinking about
    capping either the RF section of the MCU+RF entirely. Also made an
    ESP3212 module version, both will be built at the same time when the
    time comes.
    [MCU-STM32F446RET6.sch, Power.sch, Vento.kicad_pcb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]
2016-10-18 Tweaks, DRC cleared, images, readme
    Tweaked both designs according to the dev board scheamtics provided by
    Espressif in the datasheets folder. Cleared both boards of DRC
    violations, added new images and updated the readme.
    [MCU-STM32F446RET6.sch, Vento.kicad_pcb, WiFi-BLE-ESP32.sch]
2016-10-27 On/Off And Cleanup
    Onoff Switch added, PCB extended 1mm to accomodated everything. routing
    and traes cleaned up. Heat sinking ground pours added to the BQ chip
    [Power.sch, Vento.csv, Vento.kicad_pcb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]
2016-10-29 New Power Topology
    LDO swapped for one with a shutdown enable from Microchip. On/Off
    switchnow toggles the shutdown enable from the new LDO.
    [Power.sch, Vento.kicad_pcb, WiFi-BLE-ESP32.sch]
